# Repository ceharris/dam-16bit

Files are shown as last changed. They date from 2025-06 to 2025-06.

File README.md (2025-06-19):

dam-16bit
=========

This repository contains KiCad sources for 16-bit digital acquisition
module suitable for use as passive bus monitor. It is designed to be
compatible with the [icm7212m-display](https://github.com/ceharris/icm7212m-display). Using this module and the complementary display module, a 16-bit 
input can be continuously displayed in hexadecimal notation on the 
4-digit LED display.

This module uses a NE555 timer in astable mode to produce a 1 kHz 
clock. At each clock pulse a 2-bit counter is incremented. The counter
outputs are used as address lines for one unit of a 74HC139 dual 2-to-4
decoder circuit. The active low chip select outputs of the decoder are
connected to the chip select inputs of two 74HC244 octal buffers. The
74HC244 consists of two 4-bit buffer units which can be independently 
selected. The outputs of the 4-bit buffer units on each of the 74HC244
circuits are connected to the B0..3 outputs for the display module.

The 2-bit counter outputs are also used to provide the DS1 and DS2 
(digit select) inputs for the display module.

With this design, the sample rate for the 16-bit inputs is approximately
250 Hz. With each clock pulse, four bits of the input are sampled and
the result is sent to the corresponding display digit.

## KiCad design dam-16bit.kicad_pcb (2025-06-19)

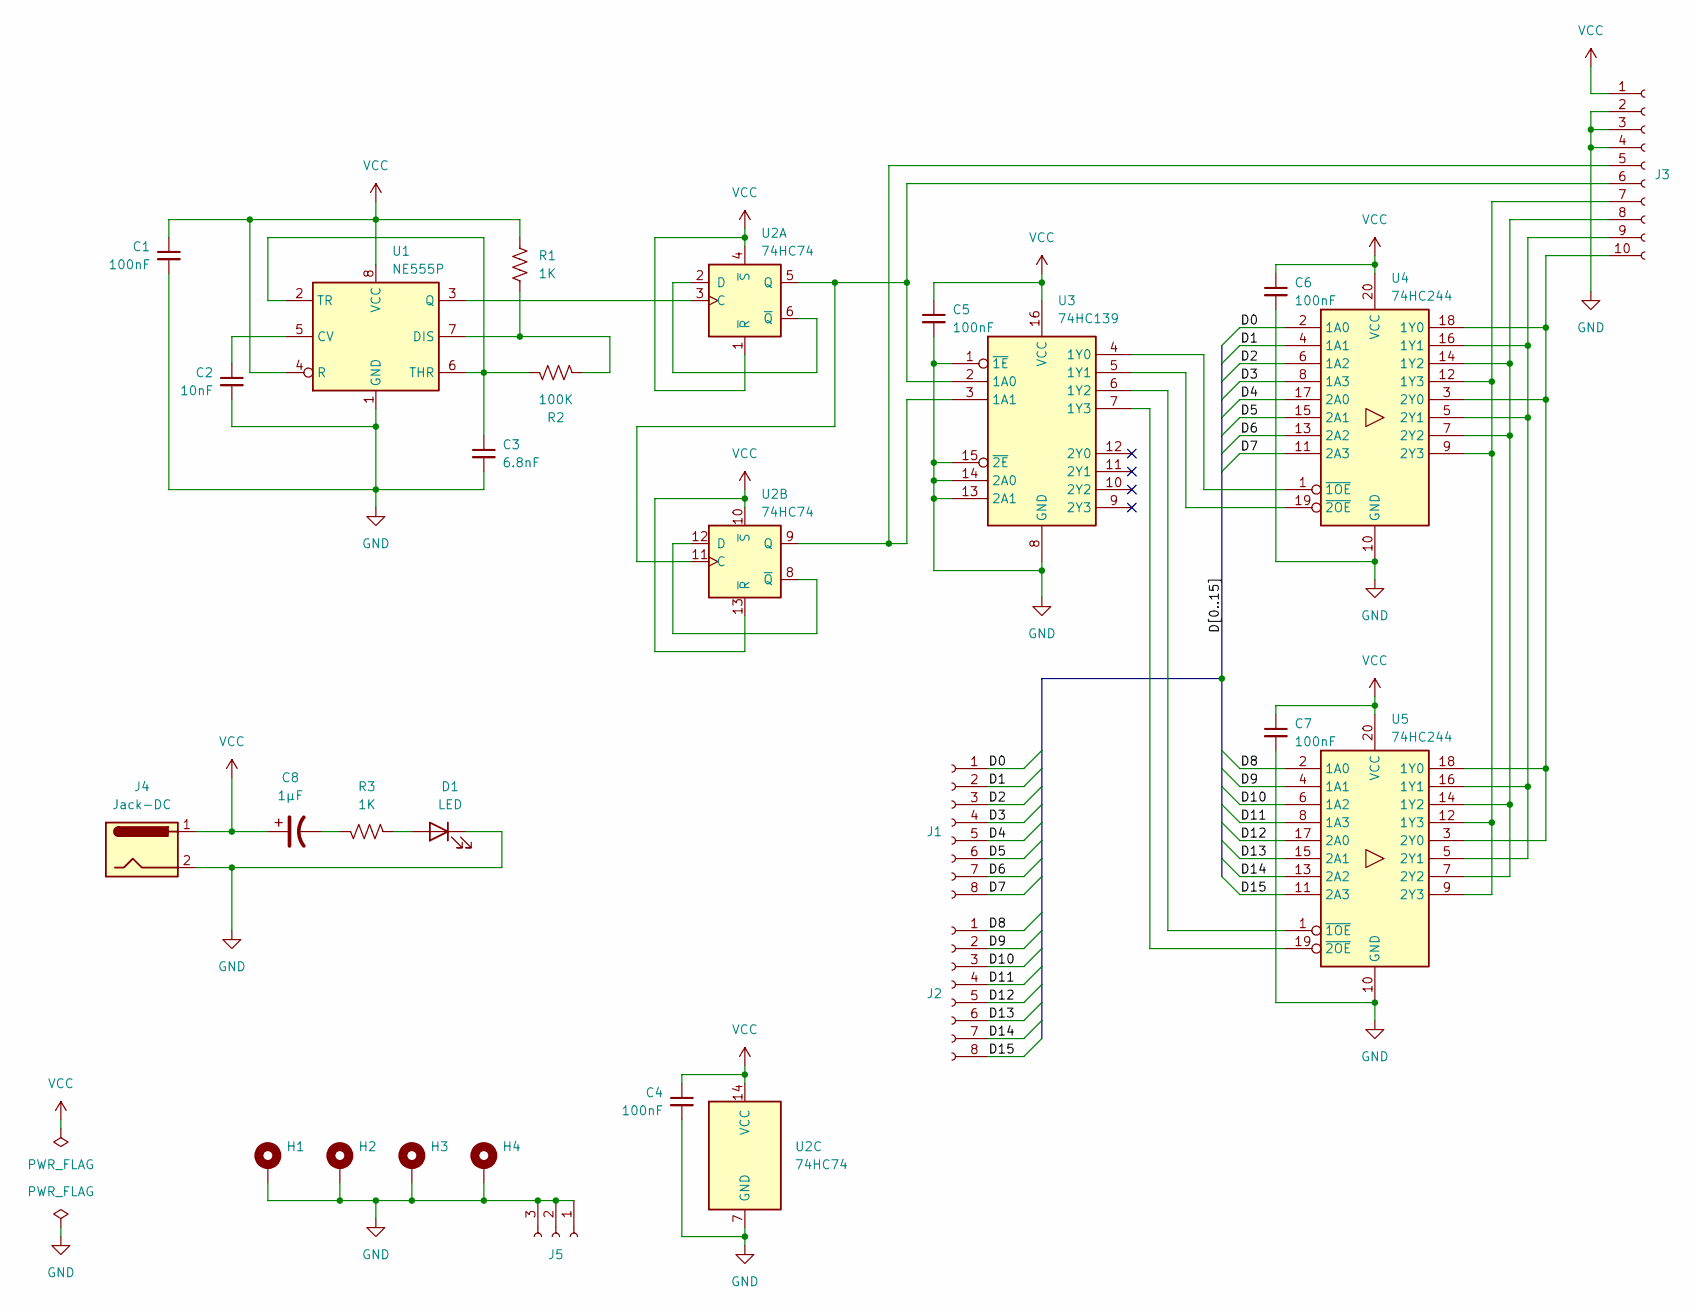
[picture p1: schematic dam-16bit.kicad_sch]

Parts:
C1, C4, C5, C6, C7: 100nF; C_Disc_D3.0mm_W1.6mm_P2.50mm
C2: 10nF; C_Disc_D3.0mm_W1.6mm_P2.50mm
C3: 6.8nF; C_Disc_D4.3mm_W1.9mm_P5.00mm
C8: 1µF; CP_Radial_D5.0mm_P2.00mm
D1: LED; LED_D3.0mm
H1, H2, H3, H4: MountingHole_Pad; MountingHole_2.2mm_M2_DIN965_Pad
J1, J2: Conn_01x08_Socket; PinSocket_1x08_P2.54mm_Vertical
J3: Conn_01x10_Socket; PinSocket_1x10_P2.54mm_Vertical
J4: Jack-DC; BarrelJack_CUI_PJ-063AH_Horizontal
J5: Conn_01x03_Socket; PinSocket_1x03_P2.54mm_Vertical
R1, R3: 1K; R_Axial_DIN0207_L6.3mm_D2.5mm_P7.62mm_Horizontal
R2: 100K; R_Axial_DIN0207_L6.3mm_D2.5mm_P7.62mm_Horizontal
U1: NE555P; DIP-8_W7.62mm_Socket
U2: 74HC74; DIP-14_W7.62mm_Socket
U3: 74HC139; DIP-16_W7.62mm_Socket
U4, U5: 74HC244; DIP-20_W7.62mm_Socket

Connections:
/D0: J1.1, U4.2 (1A0)
/D1: J1.2, U4.4 (1A1)
/D2: J1.3, U4.6 (1A2)
/D3: J1.4, U4.8 (1A3)
/D4: J1.5, U4.17 (2A0)
/D5: J1.6, U4.15 (2A1)
/D6: J1.7, U4.13 (2A2)
/D7: J1.8, U4.11 (2A3)
/D8: J2.1, U5.2 (1A0)
/D9: J2.2, U5.4 (1A1)
/D10: J2.3, U5.6 (1A2)
/D11: J2.4, U5.8 (1A3)
/D12: J2.5, U5.17 (2A0)
/D13: J2.6, U5.15 (2A1)
/D14: J2.7, U5.13 (2A2)
/D15: J2.8, U5.11 (2A3)
GND: C1.2, C2.2, C3.2, C4.2, C5.2, C6.2, C7.2, D1.1 (K), H1.1, H2.1, H3.1, H4.1, J3.2, J3.3, J3.4, J4.2, J5.1, J5.2, J5.3, U1.1 (GND), U2.7 (GND), U3.1 (~1E), U3.8 (GND), U3.13 (2A1), U3.14 (2A0), U3.15 (~2E), U4.10 (GND), U5.10 (GND)
unnamed: C8.2, R3.2
unnamed: D1.2 (A), R3.1
unnamed: J3.5, U2.9 (Q), U3.3 (1A1)
unnamed: J3.6, U2.5 (Q), U2.11 (C), U3.2 (1A0)
unnamed: J3.7, U4.9 (2Y3), U4.12 (1Y3), U5.9 (2Y3), U5.12 (1Y3)
unnamed: J3.8, U4.7 (2Y2), U4.14 (1Y2), U5.7 (2Y2), U5.14 (1Y2)
unnamed: J3.9, U4.5 (2Y1), U4.16 (1Y1), U5.5 (2Y1), U5.16 (1Y1)
unnamed: J3.10, U4.3 (2Y0), U4.18 (1Y0), U5.3 (2Y0), U5.18 (1Y0)
unnamed: C2.1, U1.5 (CV)
unnamed: R1.2, R2.2, U1.7 (DIS)
unnamed: U1.3 (Q), U2.3 (C)
unnamed: C3.1, R2.1, U1.2 (TR), U1.6 (THR)
unnamed: U2.2 (D), U2.6 (~Q)
unnamed: U2.8 (~Q), U2.12 (D)
unnamed: U3.4 (1Y0), U4.1 (~1OE)
unnamed: U3.5 (1Y1), U4.19 (~2OE)
unnamed: U3.6 (1Y2), U5.1 (~1OE)
unnamed: U3.7 (1Y3), U5.19 (~2OE)
VCC: C1.1, C4.1, C5.1, C6.1, C7.1, C8.1, J3.1, J4.1, R1.1, U1.4 (R), U1.8 (VCC), U2.1 (~R), U2.4 (~S), U2.10 (~S), U2.13 (~R), U2.14 (VCC), U3.16 (VCC), U4.20 (VCC), U5.20 (VCC)

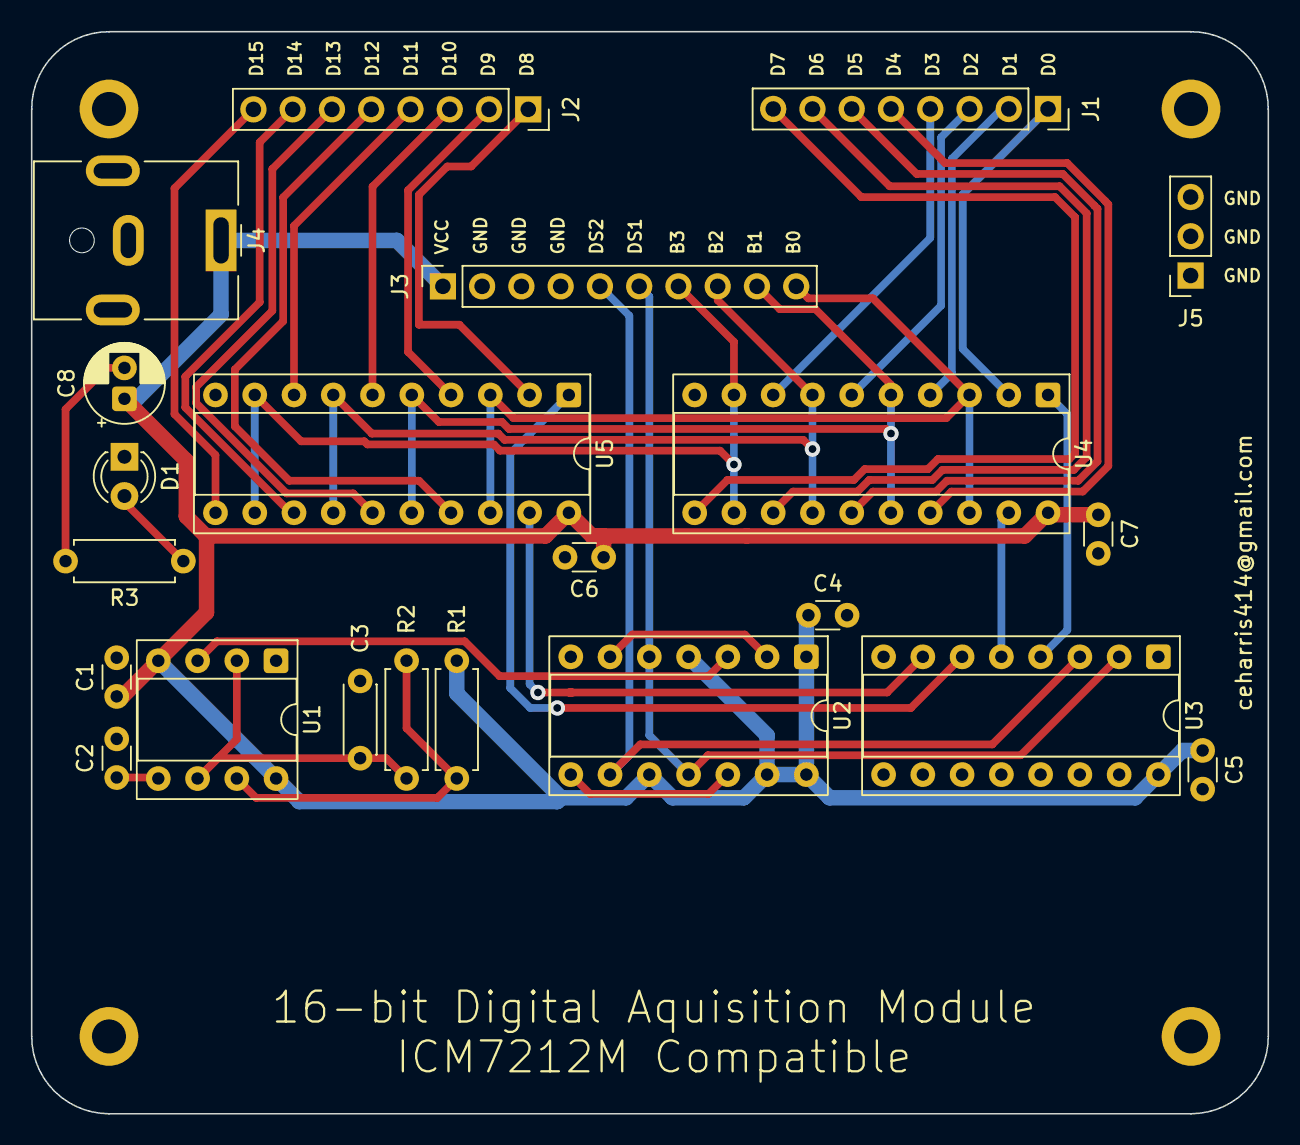
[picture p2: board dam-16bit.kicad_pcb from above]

Board: 2 copper layers, 80.0 x 70.0 mm, 26 parts (0 on the bottom side), 36 nets.
